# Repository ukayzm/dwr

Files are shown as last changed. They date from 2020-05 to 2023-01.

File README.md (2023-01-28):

# dwr (Differential Wheeled Robot)

A project to build a robot with two wheels.

# proto1

The simplest design - two wheels and one caster ball.

* 2 geared DC motors with encoder
* Arduino Uno

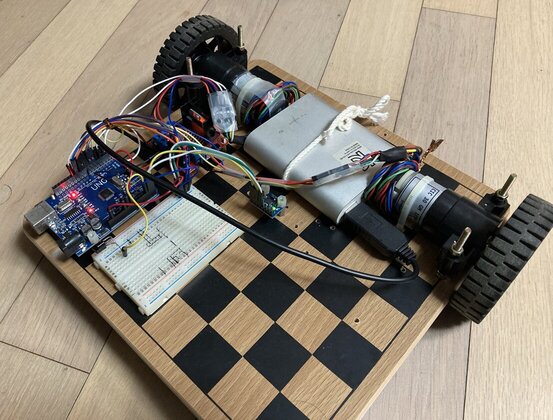
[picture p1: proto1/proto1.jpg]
proto1 (https://youtu.be/fgpBi1nglc4)


# proto2

Balancing on two wheels driven by stepper motors.

* 2 nema 17 stepper motors
* Arduino nano
* MPU6050

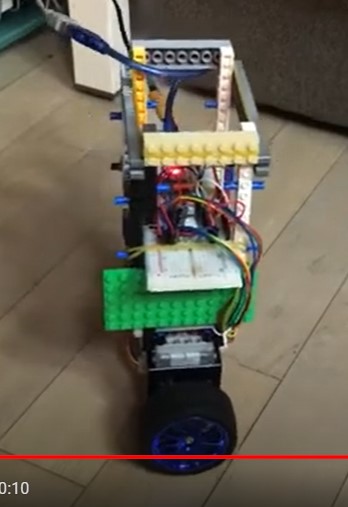
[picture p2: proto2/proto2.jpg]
proto2 (https://youtu.be/-58t6D5vS3g)


# proto3

* ESP32

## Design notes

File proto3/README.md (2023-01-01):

# proto3

ESP32 to connect with Bluetooth Joystick that will control the movement of the robot.

# Hardware 

* 2 geared DC motors with encoder
* 2 wheels, 84mm in diameter
* XXX motor driver
* ESP32
* MPU6050
* IR receiver
* 3S LiPo Battery
* Bluetooth Joystick
* a1602
* DHT11
* 7805

# Software

* src/ - main source code
* test/ - codes to test the hardware parts.
* fritzing/ - fritzing files of the hardware

## Required Library

You need to use ESP-IDF to compile the source code and upload.

Refer to [https://ukayzm.github.io/esp-idf/](https://ukayzm.github.io/esp-idf/) for how to install ESP-IDF.

## compile & upload

```bash
cd src
idf.py set-target esp32
idf.py build
idf.py flash
idf.py monitor
```

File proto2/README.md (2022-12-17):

# proto2

Two wheeled self balancing robot using stepper motors

Press the picture to see the video on YouTube.

proto2 (https://youtu.be/-58t6D5vS3g)

# Hardware 

* 2 nema 17 stepper motors
* 2 wheels, 84mm in diameter
* 2 a4988 stepper motor driver
* Arduino nano
* MPU6050
* IR receiver
* 3S LiPo battery

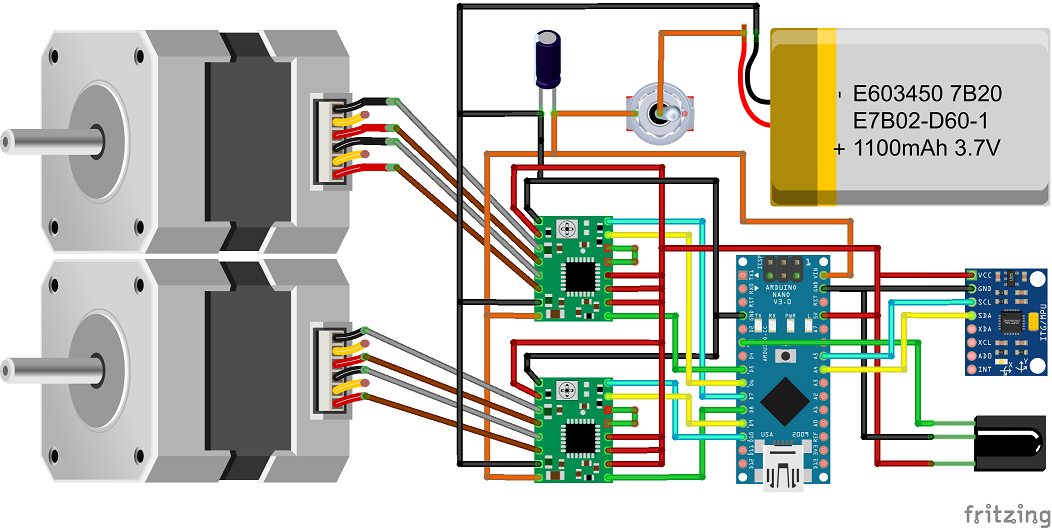
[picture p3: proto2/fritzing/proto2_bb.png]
fritzing


# Software

* sketch/ - main source code
* test/ - codes to test the hardware parts.
* fritzing/ - fritzing files of the hardware

## Required Library

* IRremote
* I2Cdev, MPU6050 from https://github.com/jrowberg/i2cdevlib

You can use Arduino standard IDE to compile the source code and upload. But I prefer to use linux terminal.

```bash
$ arduino-cli lib install IRremote
$ git clone https://github.com/jrowberg/i2cdevlib
$ cd i2cdevlib/Arduino/
$ cp -r I2Cdev/ MPU6050/ ~/Arduino/libraries/
```
## compile & upload

### Arduino Uno board

```bash
$ cd dwr/proto1
$ arduino-cli compile --fqbn arduino:avr:uno -u -p /dev/ttyACM0 sketch/
$ stty -F /dev/ttyACM0 cs8 115200 ignbrk -brkint -icrnl -imaxbel -opost -onlcr -isig -icanon -iexten -echo -echoe -echok -echoctl -echoke noflsh -ixon -crtscts
$ cat /dev/ttyACM0
```

### Arduino Uno clone

```bash
$ cd dwr/proto1
$ arduino-cli compile --fqbn arduino:avr:uno -u -p /dev/ttyUSB0 sketch/
$ stty -F /dev/ttyUSB0 cs8 115200 ignbrk -brkint -icrnl -imaxbel -opost -onlcr -isig -icanon -iexten -echo -echoe -echok -echoctl -echoke noflsh -ixon -crtscts
$ cat /dev/ttyUSB0
```

### Arduino Nano clone
```bash
$ cd dwr/proto1
$ arduino-cli compile --fqbn arduino:avr:nano:cpu=atmega328old -u -p /dev/ttyUSB0 sketch/
$ stty -F /dev/ttyUSB0 cs8 115200 ignbrk -brkint -icrnl -imaxbel -opost -onlcr -isig -icanon -iexten -echo -echoe -echok -echoctl -echoke noflsh -ixon -crtscts
$ cat /dev/ttyUSB0
```

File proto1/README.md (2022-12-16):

# proto1

The simplest design - two differential wheels and a ball caster as the third wheel

Press the picture to see the video on YouTube.

proto1 (https://youtu.be/fgpBi1nglc4)

# Hardware 

* 2 geared DC motors with encoder
* 2 wheels, 84mm in diameter
* L293N motor driver
* Arduino Uno
* MPU6050
* IR receiver
* Xiaomi Power Bank 10400mAh

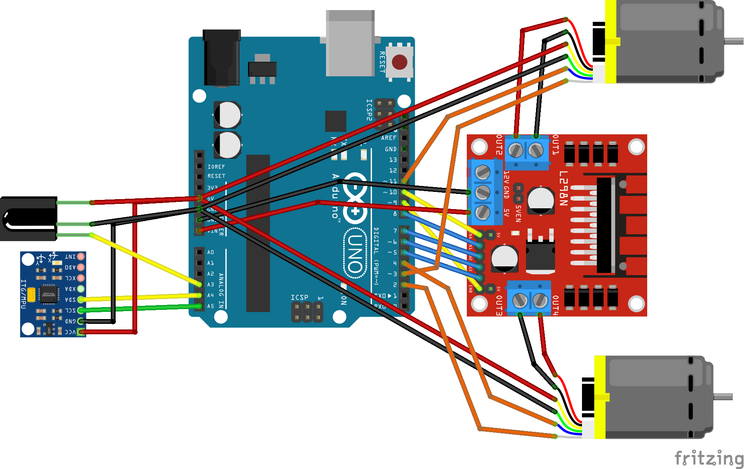
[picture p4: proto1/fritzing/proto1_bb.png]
fritzing


# Software

* sketch/ - main source code
* test/ - codes to test the hardware parts.
* fritzing/ - fritzing files of the hardware

## Required Library

* IRremote
* I2Cdev, MPU6050 from https://github.com/jrowberg/i2cdevlib

You can use Arduino standard IDE to compile the source code and upload. But I prefer to use linux terminal.

```bash
$ arduino-cli lib install IRremote
$ git clone https://github.com/jrowberg/i2cdevlib
$ cd i2cdevlib/Arduino/
$ cp -r I2Cdev/ MPU6050/ ~/Arduino/libraries/
```
## compile & upload

### Arduino Uno board

```bash
$ cd dwr/proto1
$ arduino-cli compile --fqbn arduino:avr:uno -u -p /dev/ttyACM0 sketch/
$ stty -F /dev/ttyACM0 cs8 115200 ignbrk -brkint -icrnl -imaxbel -opost -onlcr -isig -icanon -iexten -echo -echoe -echok -echoctl -echoke noflsh -ixon -crtscts
$ cat /dev/ttyACM0
```

### Arduino Uno clone

```bash
$ cd dwr/proto1
$ arduino-cli compile --fqbn arduino:avr:uno -u -p /dev/ttyUSB0 sketch/
$ stty -F /dev/ttyUSB0 cs8 115200 ignbrk -brkint -icrnl -imaxbel -opost -onlcr -isig -icanon -iexten -echo -echoe -echok -echoctl -echoke noflsh -ixon -crtscts
$ cat /dev/ttyUSB0
```

### Arduino Nano clone
```bash
$ cd dwr/proto1
$ arduino-cli compile --fqbn arduino:avr:nano:cpu=atmega328old -u -p /dev/ttyUSB0 sketch/
$ stty -F /dev/ttyUSB0 cs8 115200 ignbrk -brkint -icrnl -imaxbel -opost -onlcr -isig -icanon -iexten -echo -echoe -echok -echoctl -echoke noflsh -ixon -crtscts
$ cat /dev/ttyUSB0
```

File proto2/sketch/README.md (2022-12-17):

# Proto 2

- Arduino nano
- Pololu A4988 motor driver + 2 NEMA 17 stepper motors
- Power: 3S LiPo battery or 12V 4A adaptor
- MPU6050
- IR receiver

2-wheel-balancing-robot-using-stepper-motor (https://www.youtube.com/watch?v=-58t6D5vS3g)

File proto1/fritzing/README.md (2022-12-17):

# Fritzing File of proto1

png

You may find the custom parts in `fritzing_parts` directory.

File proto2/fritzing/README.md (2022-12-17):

# Fritzing File of proto2

png

You may find the custom parts in `fritzing_parts` directory.

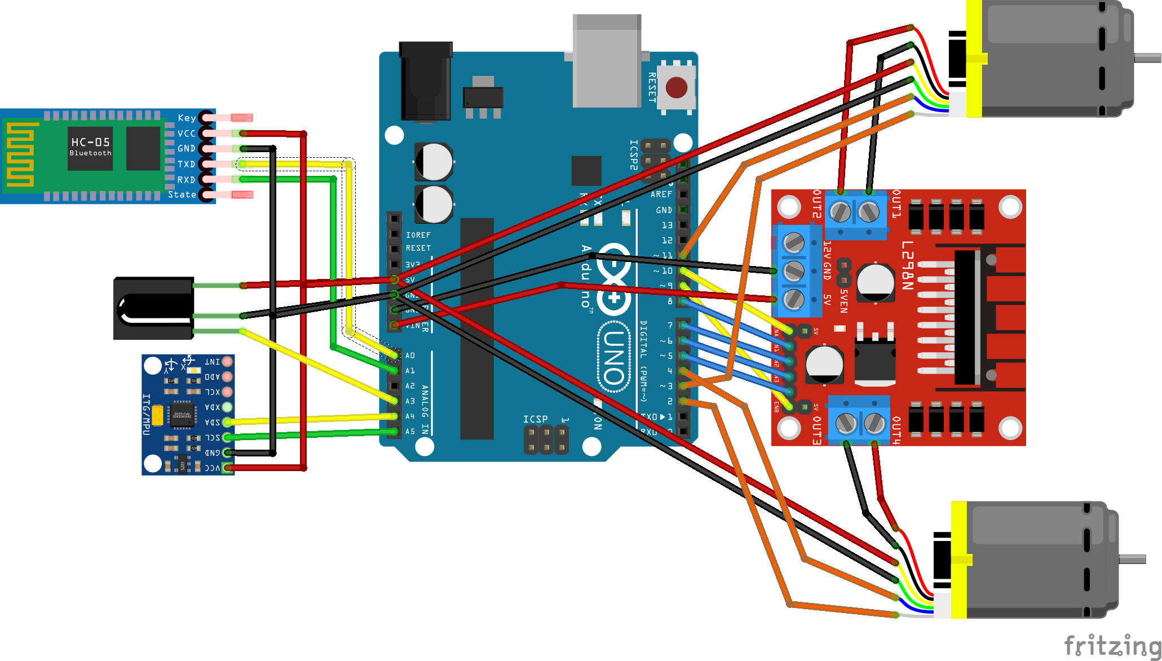
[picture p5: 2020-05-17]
proto1/fritzing/proto1_with_HC05.png

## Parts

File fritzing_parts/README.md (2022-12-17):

# Fritzing Parts to Import

It contains the parts not included by default in Fritzing. Import these parts from Fritzing.

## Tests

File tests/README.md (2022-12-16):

# Tests

Misc

# Provision Bluetooth

The default baudrate of HC-05 bluetooth serial module is 9600. We will change it to 115200 to communicate faster.

1. Upload the code `dwr/test/hc05_at_command`.
2. Remove the 5V connection to HC-05 VCC
3. Press and hold the button switch on the HC-05 module
4. Re-connect HC-05 VCC to 5V (while still pressing the button switch), the LED should come on.
5. Release the button switch and the LED should be blinking slowly on/off once every couple of seconds. This indicates AT mode. 
6. Do the following AT commands to provision HC-05

```
AT
AT+ROLE=0
AT+UART=115200,0,0
```

7. Power off and on HC-05 without pressing button. The LED should be blinking fast on/off.

Refer to [hc05_at_command/README.md](hc05_at_command/README.md) for more information about AT command of HC-05.

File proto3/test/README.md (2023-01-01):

# Test

Codes to test and calibrate the hardware of proto3 and measure the performance.

* BuiltInLED_Serial - Blink the built-in LED and measure the delay or printf() through serial using ESP-IDF.
* bluetooth_host_joystick - Connect to the joystick through BLE or Bluetooth classic.
* mpu6050-i2cdevlib - Test MPU6050 with i2cdevlib library.
* mpu6050-filter - Apply Kalman filter and complementary filter to i2cdevlib.

# Compile and Upload

All tests except Arduino_BuiltInLED_Serial uses ESP-IDF.

```bash
cd TEST_DIR
idf.py build
idf.py flash
idf.py monitor
```

# Compile and Upload with Arduino-CLI

Arduino_BuiltInLED_Serial is the same as BuiltInLED_Serial except that it uses Arduino compiler.

```bash
arduino-cli compile --fqbn esp32:esp32:esp32 -u -p /dev/ttyUSB0 BuiltInLED_Serial/
stty -F /dev/ttyUSB0 cs8 115200 ignbrk -brkint -icrnl -imaxbel -opost -onlcr -isig -icanon -iexten -echo -echoe -echok -echoctl -echoke noflsh -ixon -crtscts
cat /dev/ttyUSB0
```

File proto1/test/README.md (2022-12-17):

# Test hardware parts, connections on board, software parameters

* serial - output characters to serial port and measure the timing
* ir - test IR receiver to receive IR signal and print the received IR code
* mpu6050 - test MPU6050 in DMP mode. It reads data from MPU6050, measure the time taken by reading and prints YPR and Euler angle.
* motor_direction - test the direction of DC motors to check the wire connections.

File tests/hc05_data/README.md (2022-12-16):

# Test HC-05 in data mode

Before this, please make it sure that the baudrate of HC-05 is set as 115200 with AT command. Then set HC-05 in data mode by just pluging off and on. The LED should blink fast.

## Pairing HC-05 with Windows 10

The best instruction is [here](https://www.collideabq.com/2016/04/28/bluetooth-serial-connection-with-windows-10/).

Once the pairing is done, the LED should blink twice every couple of seconds.

If HC-05 is power-cycled, the pairing should be done again.

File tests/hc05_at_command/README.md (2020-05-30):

# Test HC-05 in AT mode

This tests HC-05 bluetooth serial module in AT mode. Basically it reads byte from bluetooth and write to serial port, and vice versa.
By this way, we can send AT command from serial port to HC-05, and print response from HC-05 to serial port.

In addition, the time taken to write to bluetooth is measured and displayed.

## Baud rate

* The baud rate in AT mode is always 38400, a fixed value.
* In the test code, the baud rate of serial port is 115200.

This difference can cause a data overflow when writing byte from serial port to bluetooth in real time. 
To avoid overflow, the byte read from serial port is saved to `line_buf`, and written to bluetooth later.

## Change HC-05 to AT mode

With the Arduino on, do the following

* Remove the 5V connection to HC-05 VCC
* Press and hold the button switch on the HC-05 module
* Re-connect HC-05 VCC to 5V (while still pressing the button switch), the LED should come
on.
* Release the button switch and the LED should be blinking slowly on/off once every couple
of seconds. This indicates AT mode. 

## Prepare serial port in host PC

Set the baud rate of serial port to 115200

```bash
$ stty -F /dev/ttyACM0 cs8 115200  ignbrk -brkint -icrnl -imaxbel -opost -onlcr -isig -icanon -iexten -echo -echoe -echok -echoctl -echoke noflsh -ixon -crtscts
```

## Sending AT command with linux terminal

You can send AT command like this
```bash
$ printf "AT\r\n" > /dev/ttyACM0
$ printf "AT+VERSION\r\n" > /dev/ttyACM0
$ printf "AT+NAME\r\n" > /dev/ttyACM0
$ printf "AT+UART\r\n" > /dev/ttyACM0
$ printf "AT+ROLE\r\n" > /dev/ttyACM0
$ printf "AT+ROLE=1\r\n" > /dev/ttyACM0
```

Be aware of the trailing `\r\n`.

## Receiving response

Open another terminal and monitor the response.
```bash
$ cat /dev/ttyACM0
Sketch:   /home/rostude/work/dwr/proto1/test_hc05_at_command/test_hc05_at_command.ino
Uploaded: May 18 2020
BTserial started at 38400
> AT
4 chars sent in 1084 usec
OK
> AT+UART
9 chars sent in 2432 usec
+UART:9600,0,0
> OK
> AT+UART=115200,0,0
20 chars sent in 5400 usec
OK
> AT+UART
9 chars sent in 2436 usec
+UART:115200,0,0
> OK
```

## Useful AT commands

| AT command | description |
| --- | --- |
| AT | check the connection |
| AT+ROLE | see role (0=slave, 1=master) (HC-05 only) |
| AT+ROLE=0 | set role as slave (HC-05 only) |
| AT+ROLE=1 | set role as master (HC-05 only) |
| AT+UART | see baudrate (HC-05 only) |
| AT+UART=115200,0,0 | set baudrate as 115200 (HC-05) |
| AT+BAUD8 | set baudrate as 115200 (HC-06), see below |
| AT+RESET | reset and exit AT mode |
| AT+ADDR | see address |
| AT+NAME | see name (HC-05 only) |
| AT+NAME=asdf | set name as asdf (HC-05) |
| AT+NAMEasdf | set name as asdf (HC-06) |
| AT+PSWD | see password (HC-05 only) |
| AT+PSWD=2987 | set password as 2987 (HC-05) |
| AT+PIN2987 | set password as 2987 (HC-06) |
| AT+RMAAD | clears any previously paired devices (HC-05) |

Setting baudrate of HC-06 is different from HC-05. To change baud rate, type AT+BAUDX, where X=1 to 9.
* 1 set to 1200bps
* 2 set to 2400bps
* 3 set to 4800bps
* 4 set to 9600bps (Default)
* 5 set to 19200bps
* 6 set to 38400bps
* 7 set to 57600bps
* 8 set to 115200bps

## Change HC-05 back to data mode

Just power off and on without pressing button switch on HC-05, then it will return to data mode.

## LED status of HC-05

* Blink once in 2 sec: Module has entered Command Mode
* Repeated Blinking: Waiting for connection in Data Mode
* Blink twice in 1 sec: Connection successful in Data Mode

## HC-05 Default Settings

* Default Bluetooth Name: HC-05
* Default Password: 1234 or 0000
* Default Communication: Slave
* Default Mode: Data Mode
* Data Mode Baud Rate: 9600, 8, N, 1
* Command Mode Baud Rate: 38400, 8, N, 1
* Default firmware: LINVOR

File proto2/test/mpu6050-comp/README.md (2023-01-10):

# MPU6050-comp (Complementary Filter)

This test measures the pitch angle with Complementary Filter and compute the elapsed time.

You can measure the time by uncommenting CHECK_ELAPSED_TIME in mpu6050.h.

The target of the loop time is max 2000 usec. If the loop time exceeds this value, `! xxxx > 2000 us` is printed.

The example of output with CHECK_ELAPSED_TIME uncommented is as the following. You can see that although the time to get the angle is around 1280 usec but `! xxxx > 2000 us` is printed because it printed too many characters.

```
3962856: 596 + 556 + 4 + 256 = 1420 usec, 82.99 ! 3996 > 2000 us
3968468: 596 + 548 + 4 + 256 = 1412 usec, 82.99 ! 3992 > 2000 us
3974076: 592 + 556 + 4 + 256 = 1416 usec, 82.99 ! 3996 > 2000 us
3979688: 588 + 556 + 4 + 256 = 1412 usec, 82.97 ! 3992 > 2000 us
3985296: 592 + 552 + 4 + 256 = 1412 usec, 82.97 ! 3996 > 2000 us
3990908: 588 + 552 + 0 + 256 = 1404 usec, 83.00 ! 3992 > 2000 us
3996520: 592 + 552 + 4 + 264 = 1416 usec, 82.98 ! 3992 > 2000 us
4002128: 588 + 548 + 4 + 256 = 1404 usec, 82.96 ! 3992 > 2000 us
4007736: 592 + 548 + 4 + 264 = 1416 usec, 82.95 ! 3996 > 2000 us
4013348: 592 + 552 + 4 + 252 = 1408 usec, 82.96 ! 3992 > 2000 us
4018960: 592 + 544 + 0 + 264 = 1404 usec, 82.93 ! 3992 > 2000 us
4024568: 588 + 552 + 4 + 256 = 1408 usec, 82.97 ! 3996 > 2000 us
4030180: 596 + 544 + 4 + 264 = 1408 usec, 82.98 ! 3992 > 2000 us
```

Comparing to Kalman Filter, it uses less time by 300 usec.

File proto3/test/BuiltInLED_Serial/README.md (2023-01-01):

# Test LED blinking and measure the delay of the printf().

The built-in LED turns on and off and test strings and results are printed out through serial port every 1 second repeatedly.

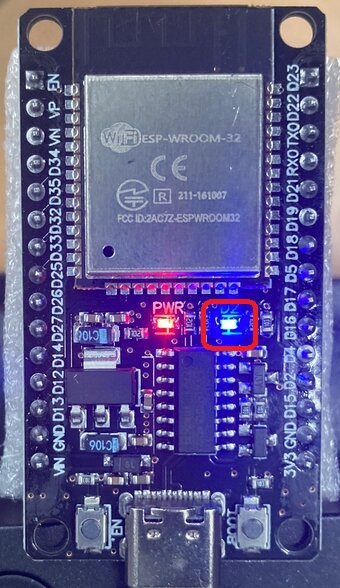
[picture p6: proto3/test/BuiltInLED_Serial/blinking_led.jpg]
Blinking built-in LED


The code was mainly taken from https://github.com/espressif/esp-idf/tree/master/examples/get-started/blink.

## Build and Run

Change `COM4` or `/dev/cu.usbserial-1130` according to your environment.

Windows: open ESP-IDF shell (CMD or PowerShell), change to the source directory, and then:

```
idf.py set-target esp32
idf.py build
idf.py -p COM4 flash monitor
```

MacOS: open a shell, change to the source directory, and then:

```
source ~/esp/esp-idf/export.sh
idf.py set-target esp32
idf.py build
idf.py -p /dev/cu.usbserial-1130 flash monitor
```

## Result

```
7.757190: ON
1234567890
 10 characters: 53 usec
1234567890123456789012345678901234567890
 40 characters: 51 usec
123456789012345678901234567890123456789012345678901234567890123456789012345678901234567890123456789012345678901234567890
 120 characters: 65 usec
1234567890123456789012345678901234567890123456789012345678901234567890123456789012345678901234567890123456789012345678901234567890123456789012345678901234567890
 160 characters: 11111 usec
1234567890123456789012345678901234567890123456789012345678901234567890123456789012345678901234567890123456789012345678901234567890123456789012345678901234567890123456789012345678901234567890123456789012345678901234567890123456789012345678901234567890
 250 characters: 11117 usec
```

It shows the delay of serial print, which is different from Arduino CLI. It is not proportional to the number of characters. The delay suddenly goes up from microseconds to milliseconds when the number of characters is bigger than 160.

One thing is clear - I can print out 120 characters with delay of only a few tens of microseconds, but only when I print it not repeatedly.

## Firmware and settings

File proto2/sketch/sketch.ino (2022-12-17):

/*
 * prj3.1 - a4988
 */
#include <IRremote.h>
#include "board.h"
#include "mpu6050.h"
#include "pid.h"

IRrecv irrecv(IR_PIN);

unsigned long loop_start_usec;

void check_ir();
extern void balancing_setup(void);
extern void balancing_loop(void);
extern void motor_set_rpm(int16_t rpm);

extern Pid AnglePid, SpeedPid;

void setup() 
{                
	Serial.begin(115200);
	Serial.println("start setup...");

	mpu6050_setup();
	Serial.println("MPU6050 initialized");

	irrecv.enableIRIn(); // Start the receiver
	Serial.println("IR initialized");

	setup_board();
	balancing_setup();

	loop_start_usec = micros();
}

void loop() 
{
#if 1
	unsigned long used_usec;

	mpu6050_loop();
	balancing_loop();
	check_ir();

	/* delay until LOOP_USEC passes */
	used_usec = micros() - loop_start_usec;
	if (used_usec < LOOP_USEC) {
		delayMicroseconds(LOOP_USEC - used_usec);
	}
	loop_start_usec = micros();
#else
#if 0
	int i;

	for (i = 0; i < 30; i++) {
		motor_set_rpm(i);
		delay(500);
	}
#else
	int i;

	for (i = 0; i < 500; i += 1) {
		motor_set_rpm(i);
		delay(5);
	}
	for (i = 500; i >= -500; i -= 1) {
		motor_set_rpm(i);
		delay(5);
	}
	for (i = -500; i < 0; i += 1) {
		motor_set_rpm(i);
		delay(5);
	}
#endif
#endif
}

#if 1
extern double fAngleKp;
extern double fAngleKi;
extern double fAngleKd;
extern double fSpeedKp;
extern double fSpeedKi;
extern double fSpeedKd;
extern void balancing_inc_tgt(void);
extern void balancing_dec_tgt(void);
extern void balancing_inc_dir(void);
extern void balancing_dec_dir(void);
extern void balancing_reset_tgtdir(void);

void check_ir()
{
  decode_results results;
  uint32_t ir_code;
  static uint32_t last_ir_code;
  static uint32_t last_ir_ms;

  results.value = 0;
  if (irrecv.decode(&results)) {
    irrecv.resume(); // Receive the next value
  }
  ir_code = results.value;

  if (ir_code == 0) {
    return;
  }
  if (ir_code != 0x4de93dc4
   && ir_code != 0x26e6c1ca
   && ir_code != 0x6d89e538
   && ir_code != 0xdad4e90b) {
    if ((last_ir_ms + 250 > millis()) && (ir_code == last_ir_code)) {
      return;
    }
  }

  if (ir_code == 0x4de93dc4) {
    Serial.println("^");
	balancing_inc_tgt();
  } else if (ir_code == 0x26e6c1ca) {
    Serial.println("v");
	balancing_dec_tgt();
  } else if (ir_code == 0x6d89e538) {
    Serial.println(">");
	balancing_inc_dir();
  } else if (ir_code == 0xdad4e90b) {
    Serial.println("<");
	balancing_dec_dir();
  } else if (ir_code == 0x7d399127) {
    Serial.println("OK");
	balancing_reset_tgtdir();
  } else if (ir_code == 0xcf98a7b6) {
    Serial.println("CH+");
	SpeedPid.setKp(SpeedPid.getKp() + SPEED_KP_STEP);
  } else if (ir_code == 0x107f5e27) {
    Serial.println("CH-");
	SpeedPid.setKp(SpeedPid.getKp() - SPEED_KP_STEP);
  } else if (ir_code == 0x68a199f0) {
    Serial.println("REC");
	SpeedPid.setKi(SpeedPid.getKi() + SPEED_KI_STEP);
  } else if (ir_code == 0xf169e8b2) {
    Serial.println("REPLAY");
	SpeedPid.setKi(SpeedPid.getKi() - SPEED_KI_STEP);
  } else if (ir_code == 0xd7d018ec) {
    Serial.println("VOL+");
	SpeedPid.setKd(SpeedPid.getKd() + SPEED_KD_STEP);
  } else if (ir_code == 0xf49b208a) {
    Serial.println("VOL-");
	SpeedPid.setKd(SpeedPid.getKd() - SPEED_KD_STEP);
  } else if (ir_code == 0x16d5cb04) {
    Serial.println("FF");
	AnglePid.setKp(AnglePid.getKp() + ANGLE_KP_STEP);
  } else if (ir_code == 0x7547960e) {
    Serial.println("NEXT");
	AnglePid.setKp(AnglePid.getKp() - ANGLE_KP_STEP);
  } else if (ir_code == 0x32939470) {
    Serial.println("PLAY/PAUSE");
	AnglePid.setKi(AnglePid.getKi() + ANGLE_KI_STEP);
  } else if (ir_code == 0x407e2e01) {
    Serial.println("STOP");
	AnglePid.setKi(AnglePid.getKi() - ANGLE_KI_STEP);
  } else if (ir_code == 0x19fd189b) {
    Serial.println("REW");
	AnglePid.setKd(AnglePid.getKd() + ANGLE_KD_STEP);
  } else if (ir_code == 0xd1921028) {
    Serial.println("PREV");
	AnglePid.setKd(AnglePid.getKd() - ANGLE_KD_STEP);
  } else if (ir_code == 0x26ecbcf3) {
    Serial.println("(0)");
  } else if (ir_code == 0x9004b206) {
    Serial.println("(1)");
  } else if (ir_code == 0xc35f14b9) {
    Serial.println("(2)");
  } else if (ir_code == 0x6bef8366) {
    Serial.println("PWR");
  } else if (ir_code == 0xbe663d0a) {
    Serial.println("MUTE");
  } else if (ir_code == 0xae7fbf1d) {
    Serial.println("TEXT");
  } else {
    Serial.println(ir_code, HEX);
  }
  last_ir_ms = millis();
  last_ir_code = ir_code;
}
#endif

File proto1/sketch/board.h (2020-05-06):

#ifndef __BOARD_H__
#define __BOARD_H__

#include <inttypes.h>
#include "dcmotor.h"


/*
 * ===================
 * PIN configuration
 * ===================
 */

/* motor encoder */
#define PIN_ENCODER_INTR_A		2
#define PIN_ENCODER_INTR_B		3
#define PIN_ENCODER_DIR_A		4
#define PIN_ENCODER_DIR_B		11

#define ENCODER_INTR_PER_REVOLUTION		657		/* 657 intr per revolution */


/* motor */
#define PIN_PWM_A				9
#define PIN_PWM_B				10
#define PIN_DIR1_MOTOR_A		6
#define PIN_DIR2_MOTOR_A		5
#define PIN_DIR1_MOTOR_B		7
#define PIN_DIR2_MOTOR_B		8

#define MOTOR_MAX_RPM			107

#define MOTOR_KP				10
#define MOTOR_KI				1
#define MOTOR_KD				1


/* Infre Red */
#define IR_PIN			A3


/* status LED */
#define STATUS_LED_PIN			LED_BUILTIN


/* loop interval (msec) */
#define LOOP_USEC     2000


/* operation mode */
enum Mode {
	MODE_READY,
	MODE_TEST_MOTOR_DIR,
	MODE_TEST_MOTOR_PWM,
	MODE_TEST_MOTOR_RPM,
	MODE_TEST_ENCODER,
	MODE_TEST_MPU6050,
	MODE_MAX,
};
extern Mode mode;

extern unsigned long cur_msec;
extern unsigned long cur_usec;


extern DcMotor motor0, motor1;


extern void setup_board(void);
extern void loop_board(void);


#endif // __BOARD_H__

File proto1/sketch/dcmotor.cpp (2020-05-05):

#include "Arduino.h"
#include "dcmotor.h"
#include "pid.h"


DcMotor::DcMotor(int _id, int16_t max_rpm, int pin_pwm, int pin_dirA, int pin_dirB)
{
	id = _id;
	pinPwm = pin_pwm;
	pinDirA = pin_dirA;
	pinDirB = pin_dirB;
	pinMode(pinPwm, OUTPUT);
	pinMode(pinDirA, OUTPUT);
	pinMode(pinDirB, OUTPUT);
	maxRpm = max_rpm;
	curPwm = 0;
	tgtRpm = 0;
}

void DcMotor::attachEncoder(Encoder *encoder)
{
	pEncoder = encoder;
    pEncoder->resetCount();
}

void DcMotor::setPwm(int16_t pwm)
{
	if (pwm > 255)
		pwm = 255;
	if (pwm < -255)
		pwm = -255;

	/* dumb speed up */
	if (pwm > 0) {
		digitalWrite(pinDirA, LOW);
		digitalWrite(pinDirB, HIGH);
	} else if (pwm < 0) {
		digitalWrite(pinDirB, LOW);
		digitalWrite(pinDirA, HIGH);
	} else {
		digitalWrite(pinDirA, LOW);
		digitalWrite(pinDirB, LOW);
	}
	curPwm = pwm;
	if (pwm < 0) {
		pwm = -pwm;
	}
	analogWrite(pinPwm, pwm);
}

void DcMotor::attachPid(Pid *_pid)
{
	pid = _pid;
}

int16_t DcMotor::getPwm(void)
{
	return curPwm;
}

void DcMotor::setRpm(int16_t rpm)
{
	Motor::setRpm(rpm);
	if (pEncoder == NULL) {
		curRpm = rpm;
	}
	if (pid == NULL) {
		setPwm((long)rpm * 255 / maxRpm);
	}
}

void DcMotor::incRpmPercent(int percent_point)
{
	Motor::incRpmPercent(percent_point);
	DcMotor::setRpm(tgtRpm);
}

void DcMotor::loop(void)
{
	unsigned long cur_usec = micros();
	prevRpm = curRpm;
    if (pEncoder) {
		pEncoder->getCountAndReset(cur_usec);
		curRpm = pEncoder->getCurRpm();
    }
	if (pid) {
		setPwmByPid();
	}
}

void DcMotor::setPwmByPid(void)
{
	int pwm = pid->compute(curRpm, tgtRpm);
	setPwm(pwm);
}

void DcMotor::incKp(float delta)
{
	if (pid) {
		pid->incKp(delta);
	}
}

void DcMotor::incKi(float delta)
{
	if (pid) {
		pid->incKi(delta);
	}
}

void DcMotor::incKd(float delta)
{
	if (pid) {
		pid->incKd(delta);
	}
}

void DcMotor::printStatus(void)
{
	Serial.print(F("\t"));
	Serial.print(curPwm);
	Serial.print(F("\t"));
	Serial.print(curRpm);
	Serial.print(F("\t"));
	Serial.print(tgtRpm);
}

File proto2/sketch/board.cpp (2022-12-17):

#include "Arduino.h"
#include "board.h"


/*
 * Enable definition to share timer 2 with IRremote library.
 * You have to modify the IRremote library
 *  - add a call to timer_isr() at the end of IRTimer() in IRremote.cpp
 */

#if defined(SHARE_TIMER2_WITH_IRREMOTE)
#define TIMER_HZ	20000
#else
#define TIMER_HZ	64000
//#define TIMER_HZ	128000
#endif

#if defined(SHARE_TIMER2_WITH_IRREMOTE)
void timer_isr();
extern void (*external_timer2_isr)();
#endif

void setup_board()
{
	Serial.println("Power supply: 3S LiPo Battery");
	Serial.println("Motor driver: a4988");

#if defined(SHARE_TIMER2_WITH_IRREMOTE)
	external_timer2_isr = timer_isr;
	Serial.println("timer_isr attached");
#else

	cli();//stop interrupts

#if defined(USE_MOTOR_TIMER1)
	//set timer1 interrupt at 1Hz
	TCCR1A = 0;// set entire TCCR1A register to 0
	TCCR1B = 0;// same for TCCR1B
	TCNT1  = 0;//initialize counter value to 0
#if 0
	// set compare match register for 1hz increments
	OCR1A = 15624;// = (16*10^6) / (1*1024) - 1 (must be <65536)

	// Set CS10 and CS12 bits for 1024 prescaler
	TCCR1B |= (1 << CS12) | (1 << CS10);  
#else
	//OCR1A = 125;  // 16Khz
	//OCR1A = 100;  // 20Khz
	//OCR1A = 80;   // 25Khz
#if (TIMER_HZ == 64000)
	OCR1A = 30;   // 64Khz
#elif (TIMER_HZ == 128000)
	OCR1A = 15;   // 128Khz
#else
#error unsupported TIMER_HZ
#endif

	// Set the timer pre-scaler
	// Generally we use a divider of 8, resulting in a 2MHz timer on 16MHz CPU
	TCCR1B = (TCCR1B & ~(0x07<<CS10)) | (2<<CS10);
#endif
	// turn on CTC mode
	TCCR1B |= (1 << WGM12);
	// enable timer compare interrupt
	TIMSK1 |= (1 << OCIE1A);
#else
	/*
	 * set timer2 interrupt at 8kHz
	 * ref: http://www.instructables.com/id/Arduino-Timer-Interrupts
	 */
	TCCR2A = 0;// set entire TCCR2A register to 0
	TCCR2B = 0;// same for TCCR2B
	TCNT2  = 0;//initialize counter value to 0
#if (TIMER_HZ == 8000)
	// set compare match register for 8khz increments
	OCR2A = 249;// = (16*10^6) / (8000*8) - 1 (must be <256)
	// Set CS21 bit for 8 prescaler
	TCCR2B |= (1 << CS21);   
#elif (TIMER_HZ == 16000)
	// set compare match register for 16khz increments
	OCR2A = 124;// = (16*10^6) / (16000*8) - 1 (must be <256)
	// Set CS21 bit for 8 prescaler
	TCCR2B |= (1 << CS21);   
#elif (TIMER_HZ == 64000)
	// set compare match register for 16khz increments
	OCR2A = 30;// = (16*10^6) / (64000*8) - 1 (must be <256)
	// Set CS21 bit for 8 prescaler
	TCCR2B |= (1 << CS21);   
#else
#error unsupported TIMER_HZ
#endif
	// turn on CTC mode
	TCCR2A |= (1 << WGM21);
	// enable timer compare interrupt
	TIMSK2 |= (1 << OCIE2A);

	Serial.println("timer2 done.");
#endif

	sei();//allow interrupts
#endif

	// setup pin
	pinMode(STEP0, OUTPUT);
	pinMode(DIR0, OUTPUT);
	pinMode(EN0, OUTPUT);
	pinMode(STEP1, OUTPUT);
	pinMode(DIR1, OUTPUT);
	pinMode(EN1, OUTPUT);

	digitalWrite(EN0, LOW);
	digitalWrite(EN1, LOW);

	Serial.println("board initialized.");
}

/*
 * ISR for timer2 runs at 8kHz frequency.
 */
uint16_t cnt, max_cnt;
#if defined(SHARE_TIMER2_WITH_IRREMOTE)
void timer_isr()
#elif defined(USE_MOTOR_TIMER1)
ISR(TIMER1_COMPA_vect)
#else
ISR(TIMER2_COMPA_vect)
#endif
{
	if (max_cnt > 0) {
		if (cnt == 0) {
			digitalWrite(STEP0, HIGH);  
			digitalWrite(STEP1, HIGH);  
		} else if (cnt == 1) {
			digitalWrite(STEP0, LOW);  
			digitalWrite(STEP1, LOW);  
		}
		cnt++;
		if (cnt > max_cnt) {
			cnt = 0;
		}
	}
}

/*
 * MICROSTEP:
 * 1: full step
 * 2: half step
 * 4: quarter step
 * 8: eights step
 * 16: sixteenth step
 */
#define MICROSTEP	16
uint16_t rpm2maxcnt(uint16_t rpm)
{
	float pps = rpm * MICROSTEP * (200.0 / 60.0);
	uint16_t maxcnt = (uint16_t)(TIMER_HZ / pps);
	if (maxcnt < 1)
		maxcnt = 1;
#if 0
	Serial.print(rpm); Serial.print(" RPM");
	Serial.print("\t= "); Serial.print(pps); Serial.print(" pulse per sec (Hz)");
	Serial.print("\t= "); Serial.print(max_cnt); Serial.print(" timer tick between pulse");
	Serial.println();
#endif
	return maxcnt;
}

void motor_set_rpm(int16_t rpm)
{
	if (rpm == 0) {
		max_cnt = 0;
		cnt = 0;
		digitalWrite(STEP0, LOW);
		digitalWrite(STEP1, LOW);
		digitalWrite(EN0, HIGH);
		digitalWrite(EN1, HIGH);
		max_cnt = 0;
	} else if (rpm < 0) {
		digitalWrite(DIR0, LOW);
		digitalWrite(DIR1, HIGH);
		digitalWrite(EN0, LOW);
		digitalWrite(EN1, LOW);
		max_cnt = rpm2maxcnt(-rpm);
	} else {
		digitalWrite(DIR0, HIGH);
		digitalWrite(DIR1, LOW);
		digitalWrite(EN0, LOW);
		digitalWrite(EN1, LOW);
		max_cnt = rpm2maxcnt(rpm);
	}
}

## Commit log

2020-04-12 proto1: change VIN, GND
    [proto1.fzz]
2020-04-13 sketch and proto2
    [proto1.fzz, proto2.fzz]
2020-04-21 initial source of proto1
    [proto1.fzz, proto2.fzz]
2020-04-25 mpu6050_dmp6, led, ir
2020-04-26 pid for speed control of DC motor
2020-05-01 fritzing proto1
    [proto1.fzz]
2020-05-05 test encoder
2020-05-17 test HC-05
    [proto1.fzz]
2020-06-01 test motor direction
2022-12-16 proto3 - LED and Serial
    proto3 - LED and Serial
2022-12-16 proto1 - picture
    proto1 - picture
    proto1 - picture
    proto1 - picture
    proto1 - picture
    [proto1.fzz, proto1_with_HC05.fzz]
2022-12-17 proto2 fritzing
    [proto2.fzz, proto3.fzz]
2022-12-24 proto2 motor_test
    proto2 motor_test
    proto2 motor_test
    [proto2.fzz]
2022-12-24 proto2 IR test
    proto2 IR test
    [proto2.fzz]
2022-12-31 mpu6050 by i2cdevlib
2023-01-01 rename to mpu6050-filter
2023-01-03 proto3 i2c-lcd-1602
2023-01-03 proto3 i2c-lcd-1602-2
2023-01-04 proto3 I2C scaning
2023-01-13 proto3 test dc-motor
